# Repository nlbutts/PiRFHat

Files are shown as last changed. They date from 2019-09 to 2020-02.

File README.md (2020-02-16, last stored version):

# PiRFHat
This project is a Pi Hat that incorporates an ST Teseo GPS receiver and a RFM9x LoRa module.

# GPS
The GPS receiver uses gpsd and is pretty straigtforward to get setup
```
apt-get install gpsd
```

Next modify **/lib/systemd/system/gpsd.service** and change the following file:
```
ExecStart=/usr/sbin/gpsd $GPSD_OPTIONS /dev/ttyS0
```

TBD working on Python code to send and receive data

# LoRa

The rf_testing.py file is a simple command line system to run BER and PER tests between two devices. It also supports simple file transfer.

## BER

To perform BER testing on the receiver do the following:
```
python rf_testing.py -n 100 -r --pirfhat
```

On the transmit do the following:
```
python rf_testing.py --pirfhat --delay=0.01
```

This will transmit 100 messages then the receiver will exit and print the BER and PER.

## File Transfer
```
python rf_testing.py --pirfhat --receivefile foo.bar
```

```
python rf_testing.py --pirfhat --sendfile foo.bar
```

# File Transfer Protocol
The file transfer protocol is very simple. You can use the LoRa header to address a particular node. The file transfer payload is defined below:

| Command | Sequence number | Payload |
| --- | ---| --- |
| Start Command (0) | Sequence Number | Bytes to transfer | 32-bit CRC | Data |
| Continuous Trasnfer (1) | Sequence Number | Data |

The **Sequence Number** is a monotonically increasing 32-bit number that indicates which packet this is.

## Start File Transfer
The **Start File Transfer** command

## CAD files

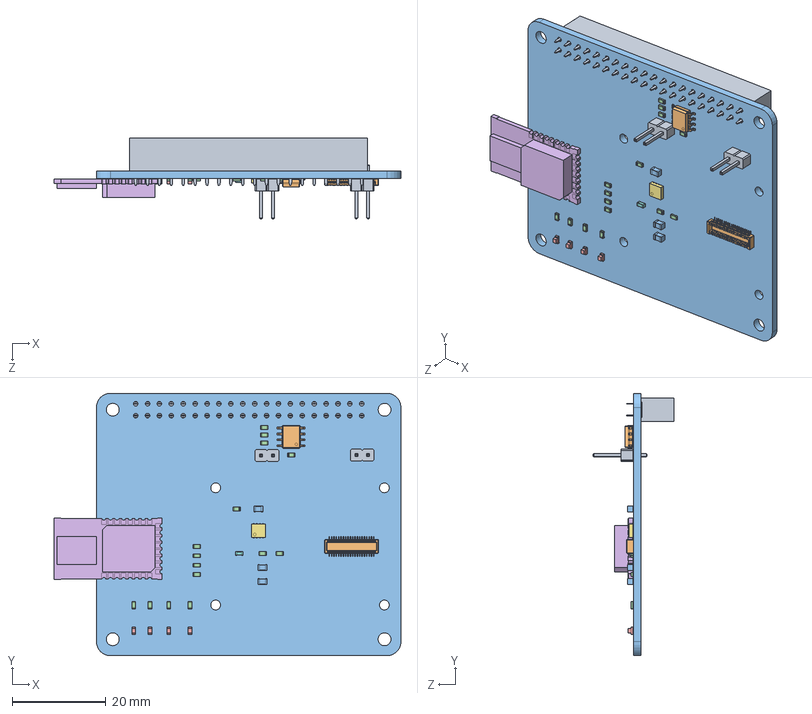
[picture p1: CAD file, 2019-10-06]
hardware/mechanical/PiRF.SLDASM
74.0 x 56.0 x 17.2 mm
SOLID.step x 2
COMPOUND.step
SOLID-0.step x 3
SOLID-1.step x 15
SOLID-2.step x 4
SOLID-3.step
SOLID-4.step
SOLID-5.step
SOLID-6.step
SOLID-7.step
COMPOUND-8.step

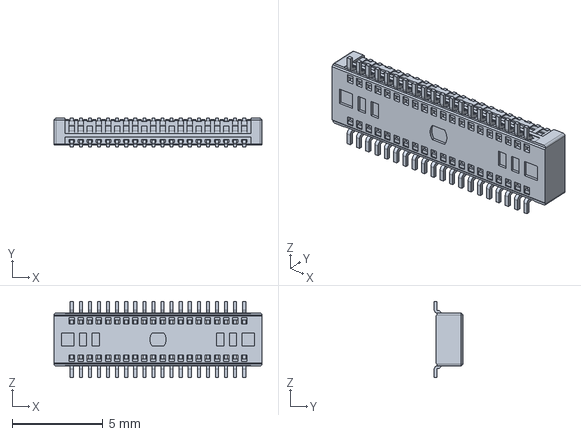
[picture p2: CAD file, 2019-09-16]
hardware/mechanical/538850408.stp
11.4 x 1.58 x 4.20 mm

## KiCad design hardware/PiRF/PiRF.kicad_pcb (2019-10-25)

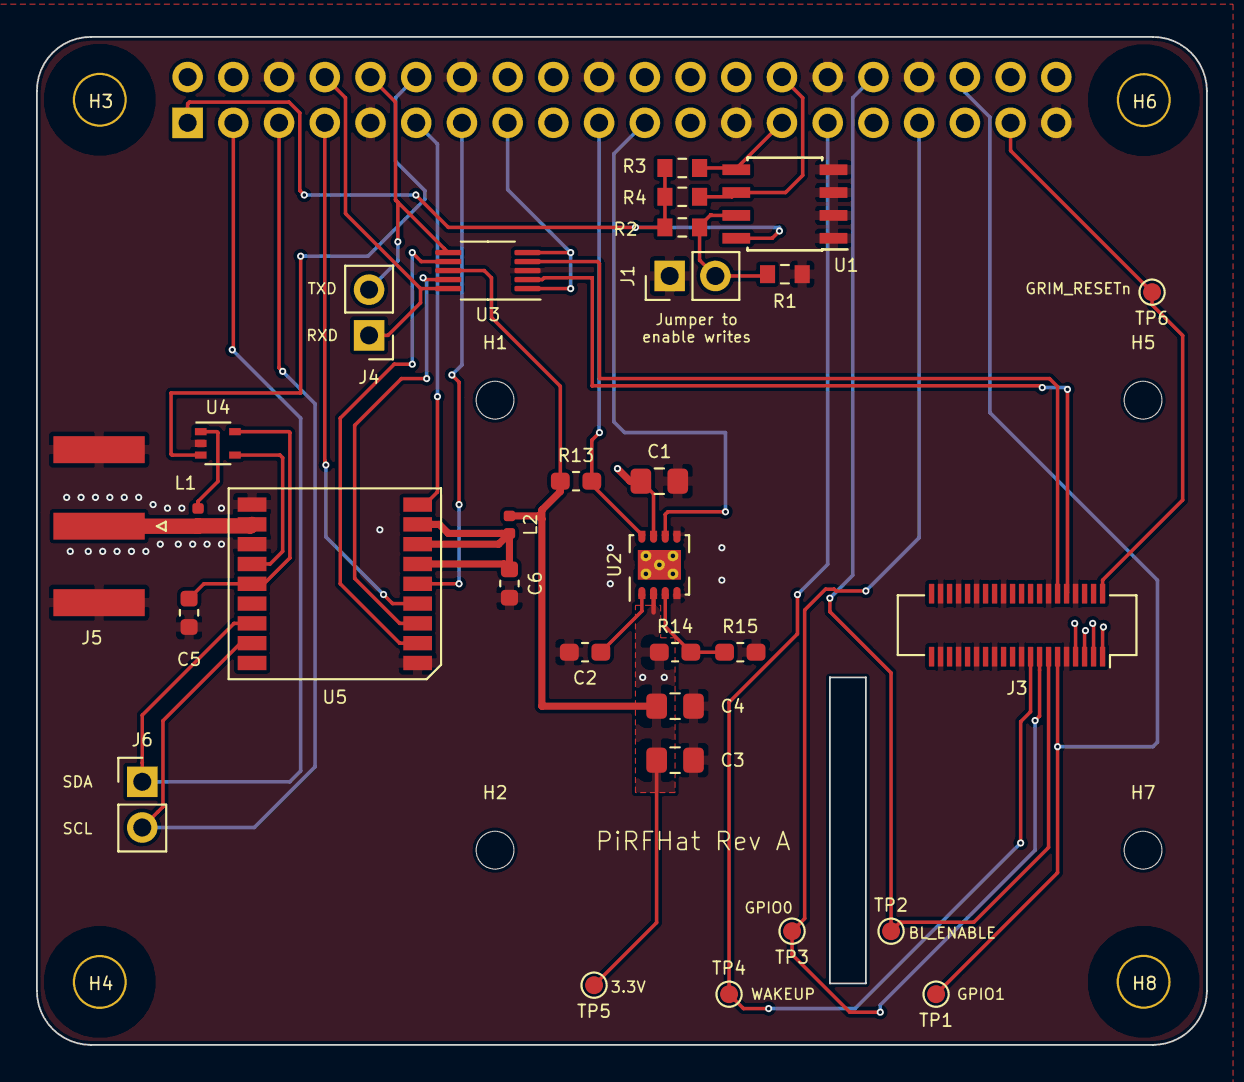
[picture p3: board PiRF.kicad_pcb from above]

Board: 2 copper layers, 65.0 x 56.0 mm, 40 parts (1 on the bottom side), 34 nets.

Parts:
C1, C3, C4: 10u; C_0805_2012Metric_Pad1.15x1.40mm_HandSolder
C2: 0.1u; C_0603_1608Metric_Pad1.05x0.95mm_HandSolder
C5, C6: 56P; C_0603_1608Metric
H1, H2, H5, H7: 3mm_Mounting_Hole; MountingHole_2.1mm
H3, H4, H6, H8: 3mm_Mounting_Hole; NPTH_3mm_ID
J1, J4, J6: CONN_01X02; PinHeader_1x02_P2.54mm_Vertical
J2: 40HAT; PinSocket_2x20_P2.54mm_Vertical
J3: Conn_02x20_Odd_Even; Molex_SlimStack_501920-4001_2x20_P0.50mm_Vertical
J5: Conn_Coaxial; SMA_Amphenol_132289_EdgeMount
L1, L2: 27n; L_0402_1005Metric
R1: DNP; R_0603_1608Metric_Pad0.84x1.00mm_HandSolder
R2: 10K; R_0603_1608Metric_Pad0.84x1.00mm_HandSolder
R3, R4: 3.9K; R_0603_1608Metric_Pad0.84x1.00mm_HandSolder
R13: R; R_0603_1608Metric_Pad1.05x0.95mm_HandSolder
R14: 15.8k; R_0603_1608Metric_Pad1.05x0.95mm_HandSolder
R15: 9.53k; R_0603_1608Metric_Pad1.05x0.95mm_HandSolder
TP1, TP2, TP3, TP4, TP5, TP6: TestPoint; TestPoint_Pad_D1.0mm
U1: CAT24C32; SOIC-8_3.9x4.9mm_P1.27mm
U2: TPS7A19; Texas_S-PVSON-N8_ThermalVias
U3: TS5A23159; VSSOP-10_3x3mm_P0.5mm
U4: TPS2294x; SOT-353_SC-70-5
U5: ST_Teseo; TESEO-LIV3R

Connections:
+3V3: C3.1, C4.1, J3.1, J3.3, J3.5, J3.7, L2.1, R13.1, R14.1, TP5.1, U2.2, U3.8
/ANT_OFF: U4.4, U5.13
/BL_ENABLE: J2.32, J3.13, TP2.1
/GPIO0: J2.33, J3.15, TP3.1
/GPIO1: J2.36, J3.11, TP1.1
/GPS_ANT_OC: J2.12, U4.3
/GPS_PPS: J2.7, U5.4
/GPS_RESETn: J2.11, U5.9
/GPS_RXD: U3.9, U5.3
/GPS_SCL: J2.5, J6.2, U5.17
/GPS_SDA: J2.3, J6.1, U5.16
/GPS_TXD: U3.7, U5.2
/GPS_WAKE: J2.13, U5.5
/GRIM_RXD: J3.10, U3.2
/GRIM_TXD: J3.12, U3.4
/HAT_3V3: J2.1, R2.1, R3.1, R4.1, U1.8
/HAT_PG: J2.19, R13.2, U2.8
/HAT_PWR_EN: J2.21, U2.6
/ID_SC_EEPROM: J2.28, R4.2, U1.6
/ID_SD_EEPROM: J2.27, R3.2, U1.5
/P5V_HAT: C1.1, J2.2, J2.4, U2.7
/RESET_N: J2.37, J3.2, TP6.1
/UART_MUX: J2.15, U3.1, U3.5
/UART_RXD: J2.8, J4.1, U3.10
/UART_TXD: J2.10, J4.2, U3.6
/VCC_RF: C5.1, U4.5, U5.14
/WAKEUP: J2.29, J3.17, TP4.1
GND: C1.2, C2.2, C3.2, C4.2, C5.2, C6.2, J1.1, J2.6, J2.9, J2.14, J2.20, J2.25, J2.30, J2.34, J2.39, J3.8, J3.9, J3.14, J3.19, J3.24, J3.25, J3.29, J3.30, J3.33, J3.34, J3.37, J3.38, J5.2, R1.2, R15.2, U1.1, U1.2, U1.3, U1.4, U2.4, U2.5, U2.9, U3.3, U4.2, U5.1, U5.10, U5.12
unnamed: C2.1, U2.1
unnamed: C6.1, L2.2, U5.6, U5.7, U5.8
unnamed: J1.2, R1.1, R2.2, U1.7
unnamed: J5.1, L1.2, U5.11
unnamed: L1.1, U4.1
unnamed: R14.2, R15.1, U2.3

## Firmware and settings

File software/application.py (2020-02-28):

from flask_socketio import SocketIO, emit
from flask import Flask, render_template, url_for, copy_current_request_context
from random import random
from time import sleep
from threading import Thread, Event
import pirf_rfm9x
from lora_xfer import *
import argparse
import os
import digitalio
import spidev
import board

__author__ = 'nlbutts'

app = Flask(__name__)
app.config['SECRET_KEY'] = 'secret!'
app.config['DEBUG'] = True

#turn the flask app into a socketio app
socketio = SocketIO(app, async_mode=None, logger=True, engineio_logger=True)

#random number Generator Thread
thread = Thread()
thread_stop_event = Event()

class LoraRx(Thread):
    def __init__(self, freq, delay, pirfhat):
        Thread.__init__(self)
        if args.pirfhat:
            print("Setting up for PiRFHat")
            self.PWR = digitalio.DigitalInOut(board.D4)
            self.RESET = digitalio.DigitalInOut(board.D6)
            self.spibus = spidev.SpiDev()
            # The PiRfHat is connected to SPI1, but not to any of the SPI CS
            self.spibus.open(1, 2)
            self.spibus.max_speed_hz = args.baudrate
            self.spibus.cshigh = False
            self.CS = digitalio.DigitalInOut(board.D8)
            global lorathread
            lorathread = True
        else:
            print("Setting up for Adafruit RFM9x")
            self.PWR = digitalio.DigitalInOut(board.D23)
            self.RESET = digitalio.DigitalInOut(board.D24)
            self.spibus = spidev.SpiDev()
            self.spibus.open(0, 1)
            self.spibus.max_speed_hz = args.baudrate
            self.spibus.cshigh = False
            self.CS = None

        self.PWR.switch_to_output()
        self.PWR.value = True
        # Initialze RFM radio
        self.rfm9x = pirf_rfm9x.RFM9x(self.spibus, self.CS, self.RESET, freq)

        # You can however adjust the transmit power (in dB).  The default is 13 dB but
        # high power radios like the RFM95 can go up to 23 dB:
        self.rfm9x.enable_crc = True
        self.rfm9x.signal_bandwidth = 500000
        self.rfm9x.spreading_factor = 7

        self.xfer = lora_xfer(self.rfm9x)

        self.delay = delay

    def run(self):
        print("***Starting LoraRX Thread")
        last_img = 0
        prev_rssi = 0
        prev_snr = 0
        while True:
            ret, rssi, snr = self.xfer.receive_file("cap.hevc", self.delay)
            if ret:
                last_img = 0
                prev_rssi = round(rssi, 1)
                prev_snr = round(snr, 1)
                decompression_str = "ffmpeg -y -i cap.hevc static/img.jpg"
                os.system(decompression_str)
                d = {}
                d['number'] = last_img
                d['rssi'] = prev_rssi
                d['snr'] = prev_snr
                socketio.emit('newnumber', d, namespace='/test')
            else:
                d = {}
                last_img += self.delay
                d['number'] = last_img
                d['rssi'] = prev_rssi
                d['snr'] = prev_snr
                socketio.emit('newnumber', d, namespace='/test')


# def randomNumberGenerator():
#     """
#     Generate a random number every 1 second and emit to a socketio instance (broadcast)
#     Ideally to be run in a separate thread?
#     """
#     #infinite loop of magical random numbers
#     print("Making random numbers")
#     while not thread_stop_event.isSet():
#         number = round(random()*10, 3)
#         #socketio.emit('newnumber', {'number': number}, namespace='/test')
#         socketio.sleep(1)


@app.route('/')
def index():
    #only by sending this page first will the client be connected to the socketio instance
    return render_template('index.html')

@socketio.on('connect', namespace='/test')
def test_connect():
    # need visibility of the global thread object
    global thread
    print('Client connected')

    #Start the random number generator thread only if the thread has not been started before.
    # if not thread.isAlive():
    #     print("Starting Thread")
    #     thread = socketio.start_background_task(randomNumberGenerator)

@socketio.on('disconnect', namespace='/test')
def test_disconnect():
    print('Client disconnected')


if __name__ == '__main__':
    infoStr = """LoRa image transfer client"""
    parser = argparse.ArgumentParser(description=infoStr)
    parser.add_argument('-f', '--freq',
                        type=float,
                        default=915.0,
                        help="RF Frequency in Mhz")
    parser.add_argument('-d', '--delay',
                        type=float,
                        default=1,
                        help="Delay between transmit packets")
    parser.add_argument('-b', '--baudrate',
                        type=int,
                        default=10000000,
                        help="Default baud rate")
    parser.add_argument('--pirfhat',
                        action='store_true',
                        help="Set if you are using the PiRfHat")
    args = parser.parse_args()

    lrx = LoraRx(args.freq, args.delay, args.pirfhat)
    lrx.start()
    socketio.run(app, host="0.0.0.0", use_reloader=False)

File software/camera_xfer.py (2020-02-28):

import os
import pirf_rfm9x
import argparse
import board
import digitalio
import time
import spidev
import picamera
from gps import *
from lora_xfer import *


def get_gps(gpsd):
    PI_LED1 = digitalio.DigitalInOut(board.D10)
    PI_LED1.switch_to_output()
    latitude = 0
    longitude = 0
    alt = 0
    report = gpsd.next()
    if report['class'] == 'TPV':
        print(report)
        try:
            PI_LED1.value = True
            latitude  = report['lat']
            longitude = report['lon']
            #alt       = report['alt']
            pass
        except Exception as e:
            print("GPS Not ready")
    return latitude, longitude, alt

def main():
    infoStr = """Script to test lora"""
    parser = argparse.ArgumentParser(description=infoStr)
    parser.add_argument('-f', '--freq',
                        type=float,
                        default=915.0,
                        help="RF Frequency in Mhz")
    parser.add_argument('-p', '--power',
                        type=int,
                        default=23,
                        help="Power to transmit in dB (23-5)")
    parser.add_argument('-d', '--delay',
                        type=float,
                        default=1,
                        help="Delay between transmit packets")
    parser.add_argument('-b', '--baudrate',
                        type=int,
                        default=10000000,
                        help="Default baud rate")
    parser.add_argument('--server',
                        action='store_true',
                        help="This unit will transmit images")
    parser.add_argument('--pirfhat',
                        action='store_true',
                        help="Set if you are using the PiRfHat")
    parser.add_argument('--cap_delay',
                        type=int,
                        default=5,
                        help="Delay between image captures")
    parser.add_argument('-q', '--quality',
                        type=int,
                        default=800000,
                        help="Compression quality for the HEVC")
    parser.add_argument('-r', '--resolution',
                        type=int,
                        default=1,
                        help="0=640, 1=1280, 2=1920, 3=3280")
    args = parser.parse_args()

    if args.pirfhat:
        PWR = digitalio.DigitalInOut(board.D4)
        RESET = digitalio.DigitalInOut(board.D6)
        spibus = spidev.SpiDev()
        # The PiRfHat is connected to SPI1, but not to any of the SPI CS
        spibus.open(1, 2)
        spibus.max_speed_hz = args.baudrate
        spibus.cshigh = False
        CS = digitalio.DigitalInOut(board.D8)
    else:
        PWR = digitalio.DigitalInOut(board.D23)
        RESET = digitalio.DigitalInOut(board.D24)
        spibus = spidev.SpiDev()
        spibus.open(0, 1)
        spibus.max_speed_hz = args.baudrate
        spibus.cshigh = False
        CS = None

    PWR.switch_to_output()
    PWR.value = True
    # Initialze RFM radio
    rfm9x = pirf_rfm9x.RFM9x(spibus, CS, RESET, args.freq)

    # You can however adjust the transmit power (in dB).  The default is 13 dB but
    # high power radios like the RFM95 can go up to 23 dB:
    rfm9x.tx_power = args.power
    rfm9x.enable_crc = True
    rfm9x.signal_bandwidth = 500000
    rfm9x.spreading_factor = 7

    xfer = lora_xfer(rfm9x)

    if args.resolution == 0:
        w = 640
        h = 480
    elif args.resolution == 1:
        w = 1280
        h = 960
    elif args.resolution == 2:
        w = 1920
        h = 1440
    else:
        w = 3280
        h = 2464

    if args.server:
        gpsd = gps(mode=WATCH_ENABLE)
        with picamera.PiCamera() as camera:
            camera.resolution = (w, h)
            #camera.resolution = (640, 480)
            camera.hflip = True
            camera.vflip = True
            while True:
                time.sleep(args.cap_delay)
                print("Getting GPS")
                latitude, longitude, alt = get_gps(gpsd)
                print("Got GPS")
                img_str = "{}\n{} {} {}".format(time.asctime(), latitude, longitude, alt)
                camera.annotate_text = img_str
                camera.annotate_background = picamera.Color(r=0, g=0, b=0)
                camera.capture("cap.jpg")
                compression_str = "ffmpeg -y -i cap.jpg -b:v {} cap.hevc".format(args.quality)
                #compression_str = "ffmpeg -y -i cap.jpg cap.webm"
                os.system(compression_str)
                xfer.send_file("cap.hevc")
    else:
        while True:
            xfer.receive_file("cap.hevc", args.delay)
            decompression_str = "ffmpeg -y -i cap.hevc cap.jpg"
            os.system(decompression_str)

if __name__ == "__main__":
    # execute only if run as a script
    main()

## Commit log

2019-09-16 Initial add
    [538850408.stp, PiRF.kicad_pcb, PiRF.sch]
2019-09-19 Updated the design. Ready to start layout.
    [538850408.stp, PiRF.kicad_pcb, PiRF.sch]
2019-09-19 Updated and started to route signals.
    [PiRF.kicad_pcb, PiRF.sch]
2019-09-20 Finished layout
    [PiRF.kicad_pcb, PiRF.sch]
2019-10-06 Added GPS to the design, haven't routed the design yet.
    [PiRF.SLDASM, PiRF.kicad_pcb, PiRF.sch]
2019-10-06 Removed the DWM1000 and replaced it with GPS.
    [PiRF.kicad_pcb, PiRF.sch]
2019-10-06 Added an info section to the silkscreen.
    [PiRF.kicad_pcb]
2019-10-06 Added a cutout for the camera.
    [PiRF.kicad_pcb]
2019-10-25 Update part numbers.
    [PiRF.kicad_pcb, PiRF.sch]
2020-02-13 Updated the rf_testing.py file to support both the Adafruit RFM9x boards and this project PiRFHat.
2020-02-17 Added a camera transfer program.

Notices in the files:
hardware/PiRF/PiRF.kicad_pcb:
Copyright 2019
